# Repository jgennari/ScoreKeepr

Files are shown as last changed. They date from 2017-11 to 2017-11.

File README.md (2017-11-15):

# ScoreKeepr
A digital, wireless scorekeeper for games like cornhole & table tennis.

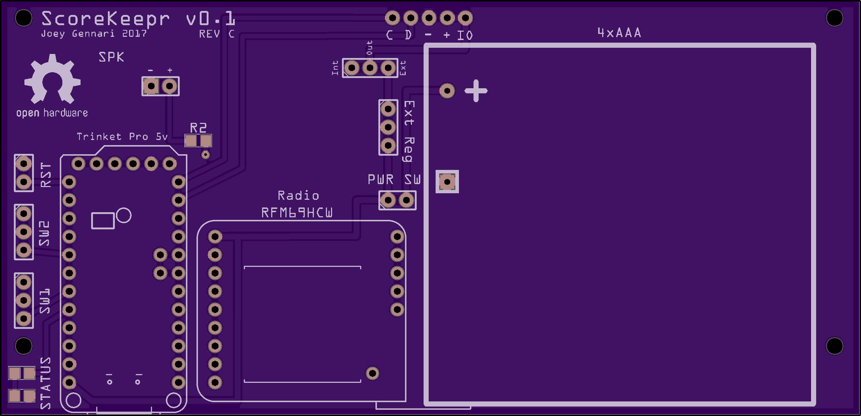
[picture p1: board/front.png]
Board Front
Final Product&nbsp;

## Overview
ScoreKeepr is a digital, wireless score keeping device for two player games where the players may be stationed apart from each other. For games like [cornhole](https://en.wikipedia.org/wiki/Cornhole) or [table tennis](https://en.wikipedia.org/wiki/Table_tennis). This was my first fully integrated hardware project, including PCB design, CAD modeling for the case, 3D printing, assembly and coding.

## Required
You can buy all the parts individually or use the Digi-Key cart I've created [here](http://www.digikey.com/short/q38b45).

* PCB [(link)](https://oshpark.com/shared_projects/CAZ9tcIK)
* Trinket Pro 5V [(link)](https://www.adafruit.com/product/2000)
* RFM69 Radio Module [(link)](https://www.adafruit.com/product/3070)
* LED 7-Segment Backpack [(link)](https://www.adafruit.com/product/1268)
* 5V Regulator [(link)](https://www.pololu.com/product/2119)
* Various switches
* Basic soldering skills
* 3D Printer

## Assembly
![Inside](https://lh3.googleusercontent.com/EB8lr5_Ue-uhq_NUh4rdfYeRYP7nRB3DBMlZgg_3J5hOfSd1uYdCLQTaeXuNpGC8c9cLIu12nuFSjJkAKhCtU4IvUhB__q3_GUOcpaGGLYo6QbFg7tiwQ45jAksJ-Zd9QVC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)

The assembly is simple. The Trinket Pro & radio module are mated to the PCB using standard .1" headers for ease of debugging. I used .1" header to connect the switches and regulator, so soldering should be very simple.

## Programming
The Trinket Pro 5V has a USB bootloader, so programming is pretty straight forward. Just load the INO file into the Arduino IDE and upload to the device. You will need the following before you can compile and upload:

* Install the following libraries in your Arduino environment:

   Bounce2 [(link)](https://github.com/thomasfredericks/Bounce2)  
   Adafruit_GFX [(link)](https://github.com/adafruit/Adafruit-GFX-Library)  
   Adafruit_LEDBackpack [(link)](https://github.com/adafruit/Adafruit_LED_Backpack)  
   RadioHead [(link)](http://www.airspayce.com/mikem/arduino/RadioHead/)  
   PinChangeInterrupt [(link)](https://github.com/NicoHood/PinChangeInterrupt)  
   LowPower [(link)](https://github.com/rocketscream/Low-Power)  
   EEPROMex [(link)](https://github.com/thijse/Arduino-EEPROMEx)  
* Install the Trinket Pro boards in the Arduino IDE [(link)](https://learn.adafruit.com/introducing-pro-trinket/setting-up-arduino-ide)

## Operation
The operation is simple. There is a power switch in the middle and two rocker switch for player 1 and player 2. Clicking the rocker switches up and down will increase and decrease the score for each player respectively. Pressing and holding the P2 down button will reset the score. Pressing and holding the P1 down button will cycle through different brightness levels. 

Click below to watch the video:

<a href="http://www.youtube.com/watch?feature=player_embedded&v=zjyllZozEEc" target="_blank">Operation Video</a>

## Future Improvements
I learned a lot during this project, and with all project there would be future improvements I would incorporate:

* Reduction in size - Due to the use of the LED backpack and Trinket, a lot of space is wasted between all the surfaces.
* Reduction in cost - Using modules and backpacks helped reduce the complexity in design, however you pay for that service. In future revisions there would be a single PCB utilizing discrete components.
* Mounting - The 3D printed case was the most simple case I could design to hold all the parts securely. There was very little thought to how it would be actually utilized. A redesign should include a mounting solution.
* Bootloader - The current implementation keeps the USB bootloader on the Trinket. However there is about a 3 second delay on boot while it checks for the presence of a USB device. This should be eliminated by burning the code directly to the MCU.
* Channels - Currently any unit listening on the 915mhz frequency with the correct encryption key can participate in the game. Ideally there would be different channels available for different games. 
* Radio - The radio works okay with a wire antenna up to about 50 feet. Any longer and you'd need a different antenna. Also, after I completed the project I found the ESP-Now which utilizes 2.4ghz wifi signal with no router. It would be way cheaper to use a ESP8266 module in this mode.

## Lessons Learned

* I designed the PCB using Fritzing and enjoyed the experience. For a subsequent project I tried Eagle and found it better suited for serious work. 
* I learned how to utilize parametric design in Fusion 360 and it really sped up the design of the case. It took about 5 iterations before I got a fit I was happy with. Without parametric design it would've been 5 redesigns from scratch.
* I misread the specs for the LED 7-segment display and overestimated the power requirements by a large magnitude. I could've used a way smaller regulator, although I do like those three-hole solutions from Pololu.
* I ordered the wrong footprint for a speaker. My intent was for the device to make an audible alert when the score changed remotely. However the part I found in Eagle wasn't the one I selected in Digi-Key. Double check your parts!
* You can provision features you may want for the PCB at no additional cost when prototyping. If it's minimal design work you won't feel bad if you drop the feature.

![Power Testing](https://lh3.googleusercontent.com/AjVLxFHPbsxVVe9WUHqJFsg0Itv99qrcK_7O76fUHGWLvgi-HI0GddeOpkAMe5iwYY-z4soHm4KBF3Rcq_0zcbrp8ysE8UfHm-ivrrlQ7wi-r1DnGCSx6geaM3CF6ygm5Ro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)

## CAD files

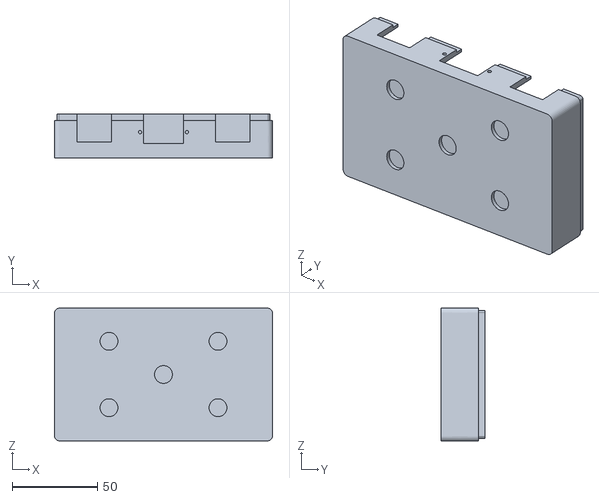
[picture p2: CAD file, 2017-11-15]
case/Bottom.stl
128.0 x 26.0 x 78.0

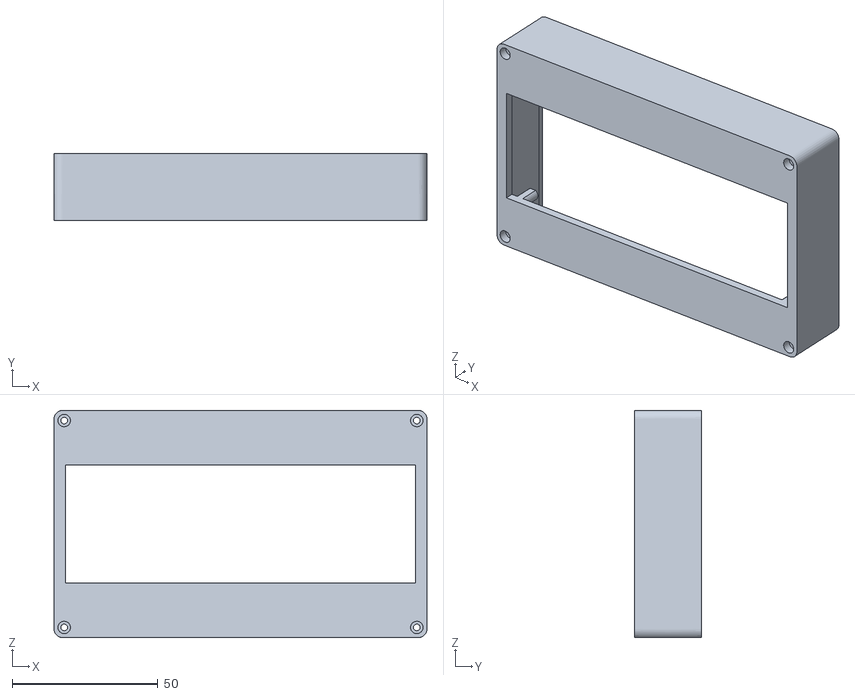
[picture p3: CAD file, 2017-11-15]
case/Top.stl
128.0 x 23.0 x 78.0

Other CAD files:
case/Bottom_v1 v3.f3d
case/Top_v1 v5.f3d

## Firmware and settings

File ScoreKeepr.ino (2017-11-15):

#include <Bounce2.h>
#include <Adafruit_GFX.h>
#include "Adafruit_LEDBackpack.h"
#include <SPI.h>
#include <RH_RF69.h>
#include <avr/sleep.h>
#include "PinChangeInterrupt.h"
#include "LowPower.h"
#include <EEPROMex.h>

#define RF69_FREQ     915.0
#define RFM69_CS      10
#define RFM69_INT     3
#define RFM69_RST     9
#define RFM69_EN      A0

RH_RF69 rf69(RFM69_CS, RFM69_INT);
Adafruit_7segment matrix = Adafruit_7segment();

Bounce P1U_db = Bounce(); 
Bounce P1D_db = Bounce(); 
Bounce P2U_db = Bounce(); 
Bounce P2D_db = Bounce(); 
const int P1U = 5;
const int P1D = 6;
const int P2U = 4;
const int P2D = A2;
unsigned long lastChange, lastScoreCheck;
int P1Score, P2Score, P1UState, P1DState, P2UState, P2DState;
boolean P1UChanged,P1DChanged,P2UChanged,P2DChanged;
int shortPress = 1500;
boolean isserver = true;
boolean sleeping = false;
int min_dim = 5;
int min_off = 10;
int level_dim = 4;
int level_bright = 12;
int P1ScoreMemory = 0;
int P2ScoreMemory = 4;
int BrightnessMemory = 8;
const int memBase = 350;

void setup() {
  matrix.begin(0x70);    
    
  pinMode(P1U,INPUT_PULLUP);  
  P1U_db.attach(P1U);
  P1U_db.interval(50);  
  attachPinChangeInterrupt(digitalPinToPinChangeInterrupt(P1U), wake, CHANGE);

  pinMode(P1D,INPUT_PULLUP);
  P1D_db.attach(P1D);
  P1D_db.interval(50);
  attachPinChangeInterrupt(digitalPinToPinChangeInterrupt(P1D), wake, CHANGE);
  
  pinMode(P2U,INPUT_PULLUP);
  P2U_db.attach(P2U);
  P2U_db.interval(50);
  attachPinChangeInterrupt(digitalPinToPinChangeInterrupt(P2U), wake, CHANGE);

  
  pinMode(P2D,INPUT_PULLUP);
  P2D_db.attach(P2D);
  P2D_db.interval(50);
  attachPinChangeInterrupt(digitalPinToPinChangeInterrupt(P2U), wake, CHANGE);
      
  pinMode(RFM69_RST, OUTPUT);
  digitalWrite(RFM69_RST, LOW);
  
  digitalWrite(RFM69_RST, HIGH);
  delay(10);
  digitalWrite(RFM69_RST, LOW);
  delay(10);

  if (!rf69.init())
    writeErrorCode(1042);
  
  if (!rf69.setFrequency(RF69_FREQ)) 
    writeErrorCode(1043);
   
  rf69.setTxPower(20, true);
  
  uint8_t key[] = { 0x29, 0x7F, 0x03, 0x04, 0x05, 0x06, 0x11, 0x08,
                    0x01, 0x15, 0x03, 0x04, 0x05, 0x06, 0x04, 0x08};
  rf69.setEncryptionKey(key);
    
  matrix.print(10000, DEC);
  matrix.writeDisplay();
  delay(500);
  
  matrix.clear();
  matrix.writeDisplay();

  if (!EEPROM.isReady())
    writeErrorCode(1044);

  
  EEPROM.setMemPool(memBase, EEPROMSizeATmega328);
  P1Score = EEPROM.readInt(memBase+P1ScoreMemory);
  P2Score = EEPROM.readInt(memBase+P2ScoreMemory);

  if (P1Score < 0
      || P1Score > 99
      || P2Score < 0
      || P2Score > 99){
      
    EEPROM.writeInt(memBase+P1ScoreMemory,0);
    EEPROM.writeInt(memBase+P2ScoreMemory,0);  
    P1Score = 0;
    P2Score = 0;
  }      
  
  if (P1Score < 0)
    P1Score = 0;
    
  if (P2Score < 0)
    P2Score = 0;
    
  level_bright = EEPROM.readInt(memBase+BrightnessMemory);
  if (level_bright < 0)
    level_bright = 12;    
  matrix.setBrightness(level_bright);  
  
  lastChange = millis();    
}

void parseScore(char recv[]) {
  matrix.writeDigitRaw(2, 0x08);  
  matrix.writeDisplay();
      
  char p1s_[5];
  memcpy(p1s_, &recv[0], 5);
  p1s_[3] = '\0';

  char p2s_[3];
  memcpy(p2s_, &recv[3], 2);
  p2s_[3] = '\0';
  
  int i;
  i = strtol(p1s_, NULL, 10);
  
  int x;
  x = strtol(p2s_, NULL, 10);

  if ((P1Score > 9 && i < 9) || (P2Score > 9 && x <9))
    matrix.clear();
    
  P1Score = i;
  P2Score = x;

  saveScore();
  lastChange = millis();
  delay(50);
  
  matrix.writeDigitRaw(2, 0x00);
  matrix.writeDisplay();
}

void sendScore() {
  matrix.writeDigitRaw(2, 0x04);
  matrix.writeDisplay();

  char radiopacket[20];
  sprintf(radiopacket, "%02d:%02d", P1Score, P2Score);
    
  rf69.send((uint8_t *)radiopacket, strlen(radiopacket));
  rf69.waitPacketSent();

  delay(50);
  matrix.writeDigitRaw(2, 0x00);
  matrix.writeDisplay();
}

void writeErrorCode(int errorcode) {  
  matrix.clear();
  matrix.writeDisplay();
  matrix.print(errorcode,DEC);
  matrix.writeDisplay();
  while(1);
}

void changeScore(char player, char dir) {
  switch(player) {
    case '1':
      switch(dir) {
        case 'U':
          P1Score++;
          break;
        case 'D':
          P1Score--;
          break;
      }
      break;
    case '2':
      switch(dir) {
        case 'U':
          P2Score++;
          break;
        case 'D':
          P2Score--;
          break;
      }
      break;
  }
  
  sendScore();
  saveScore();
}

void saveScore() {
  EEPROM.writeInt(memBase+P1ScoreMemory,P1Score);
  EEPROM.writeInt(memBase+P2ScoreMemory,P2Score);  
}

void loop() {   
  if (lastChange > 0 && millis() - lastChange > (min_off * 60000)) {
    matrix.clear();
    matrix.writeDisplay();     
    LowPower.powerDown(SLEEP_FOREVER, ADC_OFF, BOD_OFF);
    sleeping = true;   
  } 
  else if (lastChange > 0 && millis() - lastChange > (min_dim * 60000)) {
    matrix.setBrightness(level_dim);  
  } 
  else {
    matrix.setBrightness(level_bright);      
  }
  
  P1UChanged = P1U_db.update();
  P1DChanged = P1D_db.update();
  P2UChanged = P2U_db.update();
  P2DChanged = P2D_db.update();

  if (P1UChanged || P1DChanged || P2UChanged || P2DChanged)
    lastChange = millis();

  int duration = millis()-lastChange;
  int P1UState = P1U_db.read();
  int P1DState = P1D_db.read();
  int P2UState = P2U_db.read();
  int P2DState = P2D_db.read();

  if (P1U_db.rose() && P1UChanged && duration < shortPress) 
    changeScore('1', 'U');
  else if (P1D_db.rose() && P1DChanged && duration < shortPress && P1Score > 0) 
    changeScore('1', 'D');
  else if (P2U_db.rose() && P2UChanged && duration < shortPress) 
    changeScore('2', 'U');
  else if (P2D_db.rose() && P2DChanged && duration < shortPress && P2Score > 0) 
    changeScore('2', 'D');
  else if (P2DState == LOW && duration > shortPress) 
    resetScores();
  else if (P1DState == LOW && duration > shortPress) 
    cycleBrightness();

  uint8_t buf[RH_RF69_MAX_MESSAGE_LEN];
  uint8_t len = sizeof(buf);
    
  if (rf69.waitAvailableTimeout(50))  {       
    if (rf69.recv(buf, &len)) {
      parseScore((char *)buf);
    }
  }

  matrix.clear();
  writeScore(P1Score,1);
  writeScore(P2Score,4);

  if (!sleeping)
    matrix.writeDisplay();
}

void resetScores() {
  P1Score = 0;
  P2Score = 0;
  sendScore();
  saveScore();
  matrix.clear();
  matrix.writeDisplay();
  lastChange = millis();
}

void cycleBrightness() {
  level_bright++;
  
  if (level_bright > 15)
    level_bright = 1;
    
  matrix.setBrightness(level_bright);
  EEPROM.writeInt(memBase+BrightnessMemory, level_bright);
  
  matrix.clear();
  matrix.println(level_bright);
  matrix.writeDisplay();
  
  delay(500);
  matrix.clear();
  matrix.writeDisplay();
}

void writeScore(int score, int dpos) {
  int value = score;
  int itteration = 0;
  
  if (value == 0)
    matrix.writeDigitNum(dpos-itteration,0,false);
    
  while (value > 0) {
    int digit = value % 10;
    matrix.writeDigitNum(dpos-itteration,digit,false);
    value /= 10;
    itteration++;
  }
}

void wake() {
  sleeping = false;
  lastChange = millis();
}

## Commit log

2017-10-21 Added Fritzing sketch
    [CornholeKeep.fzz]
2017-10-22 Added battery holder
    [CornholeKeep1.fzz, CornholeKeep2.fzz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]
2017-10-23 CHanges to board
    [CornholeKeep2.fzz]
2017-11-09 Added source
    [CornholeKeep2.fzz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]
2017-11-15 Fixed bugs when sending score and not saved.
    [Counter.ino]
2017-11-15 Added picture of board
2017-11-15 Updated readme, added CAD & STL files for case
    [Bottom.stl, Bottom_v1 v3.f3d, CornholeKeep.fzz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]
